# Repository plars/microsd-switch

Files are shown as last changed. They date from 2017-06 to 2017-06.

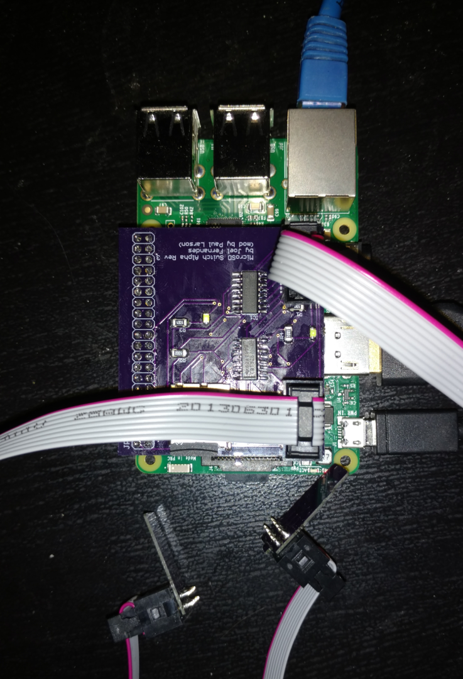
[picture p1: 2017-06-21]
pictures/microsd-switcher-pihat.png

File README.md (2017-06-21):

## MicroSD Switch

This a derivative work of a similar project by Joel Fernandes.  You can find
his original works that this is based on at:
https://github.com/joelagnel/microsd-switch

The main changes I made were to use 2x4 IDC headers instead of 1x8 rows,
and I also removed the usb/ftdi based switching in favor of a 40pin
connector so that I could use it as a RPI2/3 hat. It's not a proper hat
layout at the moment with eeprom or recommended board layout because it's
a work in progress, but the prototypes fit nicely as it is now.

To switch between host and target, it is currently wired to use GPIO 12

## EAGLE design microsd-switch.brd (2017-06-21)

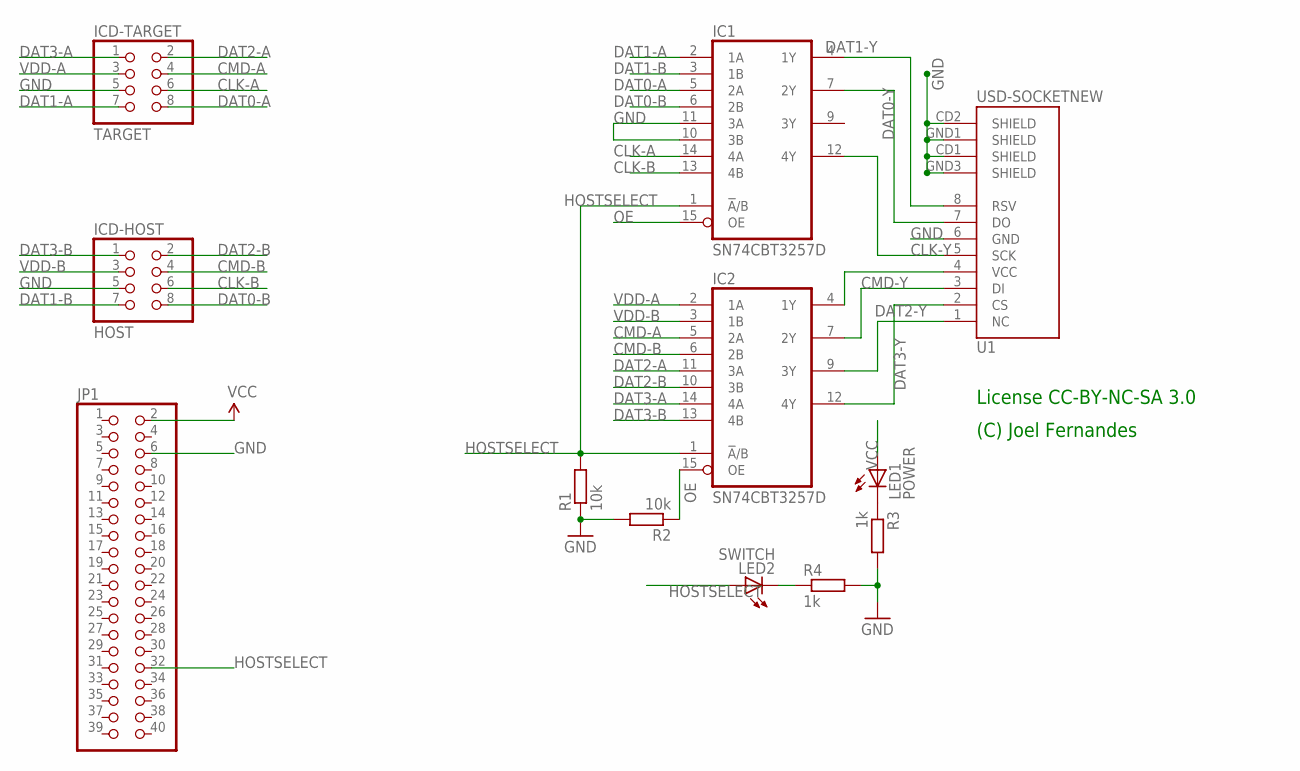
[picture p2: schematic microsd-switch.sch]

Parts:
IC1, IC2: SN74CBT3257D; SO16
ICD-HOST: HOST; 2X04
ICD-TARGET: TARGET; 2X04
JP1: PINHD-2X20; 2X20
LED1: POWER; CHIP-LED0805
LED2: SWITCH; CHIP-LED0805
R1, R2: 10k; R1206
R3, R4: 1k; R1206
U1: USD-SOCKETNEW; MICRO-SD-SOCKET-PP

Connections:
CLK-A: IC1.14 (4A), ICD-TARGET.6
CLK-B: IC1.13 (4B), ICD-HOST.6
CLK-Y: IC1.12 (4Y), U1.5 (SCK)
CMD-A: IC2.5 (2A), ICD-TARGET.4
CMD-B: IC2.6 (2B), ICD-HOST.4
CMD-Y: IC2.7 (2Y), U1.3 (DI)
DAT0-A: IC1.5 (2A), ICD-TARGET.8
DAT0-B: IC1.6 (2B), ICD-HOST.8
DAT0-Y: IC1.7 (2Y), U1.7 (DO)
DAT1-A: IC1.2 (1A), ICD-TARGET.7
DAT1-B: IC1.3 (1B), ICD-HOST.7
DAT1-Y: IC1.4 (1Y), U1.8 (RSV)
DAT2-A: IC2.11 (3A), ICD-TARGET.2
DAT2-B: IC2.10 (3B), ICD-HOST.2
DAT2-Y: IC2.9 (3Y), U1.1 (NC)
DAT3-A: IC2.14 (4A), ICD-TARGET.1
DAT3-B: IC2.13 (4B), ICD-HOST.1
DAT3-Y: IC2.12 (4Y), U1.2 (CS)
GND: IC1.8 (GND), IC1.10 (3B), IC1.11 (3A), IC2.8 (GND), ICD-HOST.5, ICD-TARGET.5, JP1.6, R1.1, R2.2, R3.2, R4.2, U1.6 (GND), U1.CD1 (SHIELD), U1.CD2 (SHIELD), U1.GND1 (SHIELD), U1.GND3 (SHIELD)
HOSTSELECT: IC1.1 (!A!/B), IC2.1 (!A!/B), JP1.32, LED2.A, R1.2
unnamed: IC2.4 (1Y), U1.4 (VCC)
unnamed: LED1.C, R3.1
unnamed: LED2.C, R4.1
OE: IC1.15 (OE), IC2.15 (OE), R2.1
VCC: IC1.16 (VCC), IC2.16 (VCC), JP1.2, LED1.A
VDD-A: IC2.2 (1A), ICD-TARGET.3
VDD-B: IC2.3 (1B), ICD-HOST.3

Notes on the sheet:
License CC-BY-NC-SA 3.0
(C) Joel Fernandes

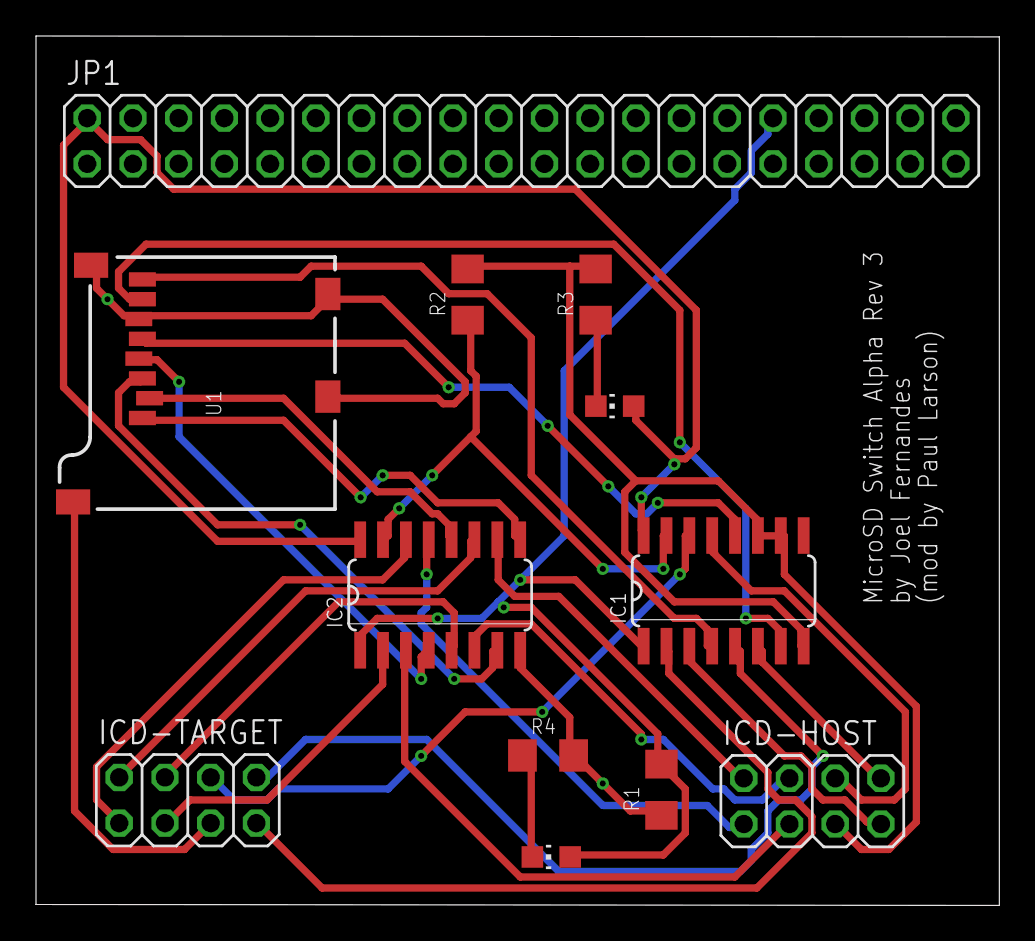
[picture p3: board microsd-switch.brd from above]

Board: 2 copper layers, 53.5 x 48.3 mm, 12 parts (0 on the bottom side), 27 nets.

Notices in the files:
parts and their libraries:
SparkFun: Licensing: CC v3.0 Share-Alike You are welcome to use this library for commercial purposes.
